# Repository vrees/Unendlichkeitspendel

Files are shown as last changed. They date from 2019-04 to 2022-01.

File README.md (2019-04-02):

GitHub Logo

Maker Media GmbH
*** 

# Unendlichkeitspendel

Ein faszinierender Hingucker ist das Pendel-Interruptus,
das ewig pendelt und nie mit der rotierenden Lochscheibe
kollidiert, die es immer wieder durchqueren muss.

von Martin Simeth

Den vollständigen Artikel mit der Bauanleitung gibt es in der Make-Ausgabe 2/19

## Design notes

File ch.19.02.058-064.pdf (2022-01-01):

# Unendlichkeits-Pendel

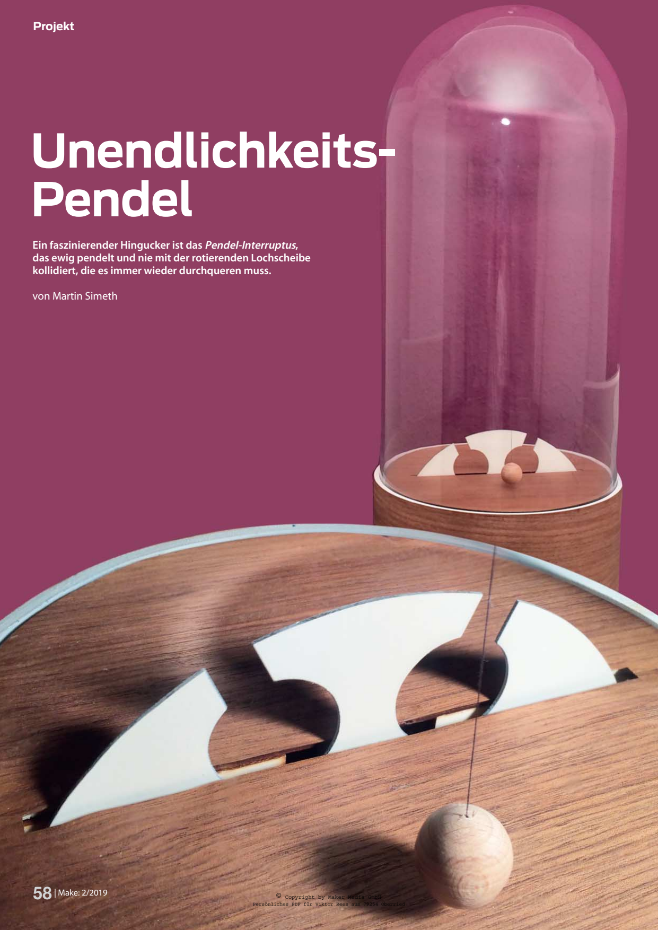
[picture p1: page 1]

58| Make: 2/2019

### Projekt

Ein faszinierender Hingucker ist das Pendel-Interruptus, das ewig pendelt und nie mit der rotierenden Lochscheibe kollidiert, die es immer wieder durchqueren muss.

von Martin Simeth

© Copyright by Maker Media GmbH

Persönliches PDF für Viktor Rees aus 79254 Oberried

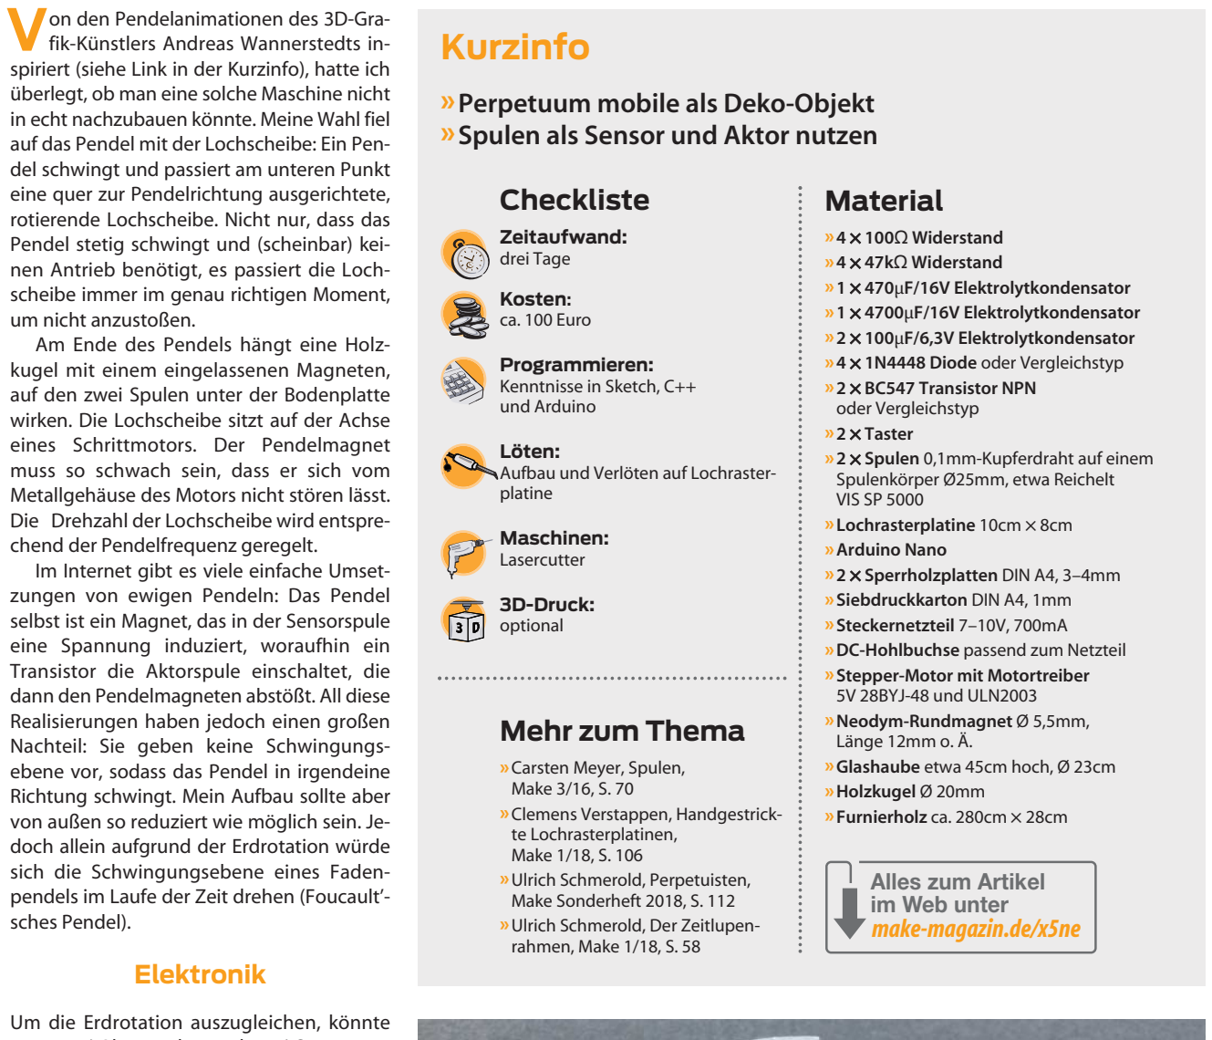
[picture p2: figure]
Von den Pendelanimationen des 3D-Gra-; fik-Künstlers Andreas Wannerstedts in-; eine quer zur Pendelrichtung ausgerichtete,; um nicht anzustoßen. Am Ende des Pendels hängt eine Holz - kugel mit einem eingelassenen Magneten,; eines Schrittmotors. Der Pendelmagnet muss so schwach sein, dass er sich vom; chend der Pendelfrequenz geregelt.; zungen von ewigen Pendeln: Das Pendel; eine Spannung induziert, woraufhin ein Transistor die Aktorspule einschaltet, die; Realisierungen haben jedoch einen großen Nachteil: Sie geben keine Schwingungs -; sich die Schwingungsebene eines Faden-; sches Pendel).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

spiriert (siehe Link in der Kurzinfo), hatte ich überlegt, ob man eine solche Maschine nicht in echt nachzubauen könnte. Meine Wahl fiel auf das Pendel mit der Lochscheibe: Ein Pendel schwingt und passiert am unteren Punkt

rotierende Lochscheibe. Nicht nur, dass das Pendel stetig schwingt und (scheinbar) keinen Antrieb benötigt, es passiert die Lochscheibe immer im genau richtigen Moment,

auf den zwei Spulen unter der Bodenplatte wirken. Die Lochscheibe sitzt auf der Achse

Metallgehäuse des Motors nicht stören lässt. Die Drehzahl der Lochscheibe wird entspre-

Im Internet gibt es viele einfache Umset-

selbst ist ein Magnet, das in der Sensorspule

dann den Pendelmagneten abstößt. All diese

ebene vor, sodass das Pendel in irgendeine Richtung schwingt. Mein Aufbau sollte aber von außen so reduziert wie möglich sein. Jedoch allein aufgrund der Erdrotation würde

pendels im Laufe der Zeit drehen (Foucault’ -

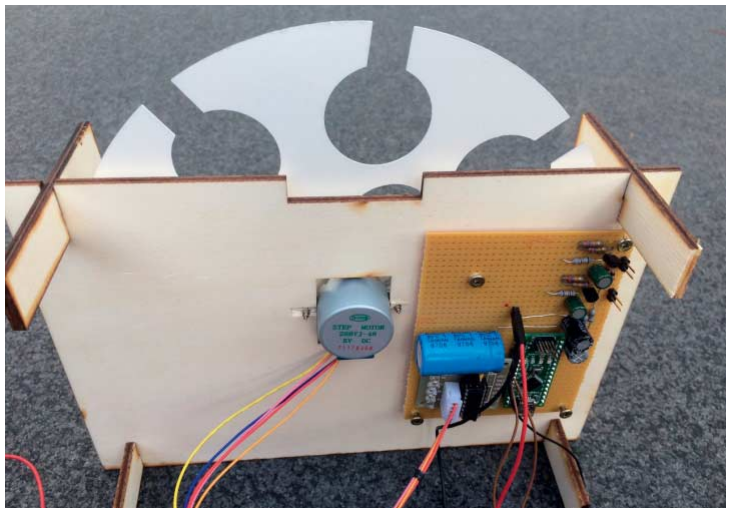
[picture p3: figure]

man zwei Aktorspulen und zwei Sensorspulen nutzen. Die intelligentere Lösung ist es, nur zwei Spulen einzubauen und diese abwechselnd sowohl als Sensor- als auch als Aktorspule einzusetzen. Die Steuerung hierfür übernimmt ein Arduino Nano, der über ein wenig Elektronik mit den Spulen verbunden wird.
Für den Spulenkörper habe ich gebräuchliche Lautsprecherspulen verwendet, bei denen ich den originalen Draht gegen 0,1mm-Kupferdraht ausgetauscht und davon so viel Draht aufgewickelt habe, bis der Spulenkörper voll war. Die exakte Impedanz der Spulen ist nicht wichtig, da die Software Abweichungen gut ausgleicht. Allerdings ist eine hohe Induktivität der Spulen für das Pendel hilfreich.
Über R4 und D1 beziehungsweise R8 und D3 werden die Kondensatoren C1 und C2 aufgeladen. Dabei prüft ein A/D-Wandler des Arduinos an den Spannungsteilern R2/R3 und R6/R7 permanent, ob eine Spannungs-
Make: 2/2019 | 59

Montage der Teile für die Lochscheibe und aufgebaute Elektronik

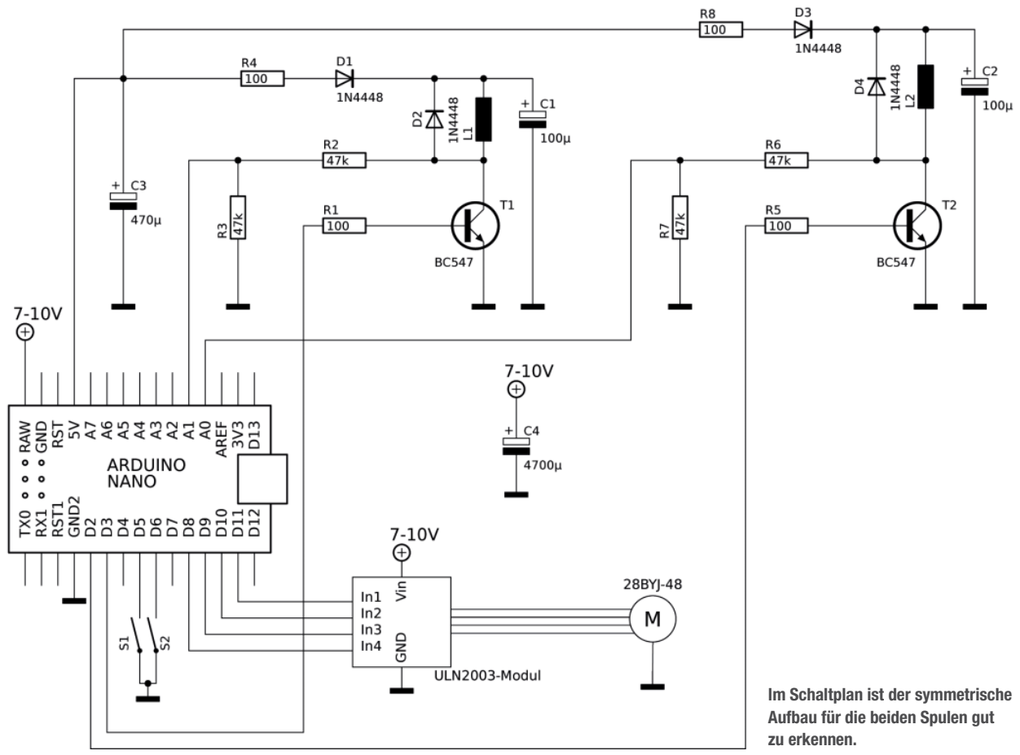
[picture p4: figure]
Im Schaltplan ist der symmetrische Aufbau für die beiden Spulen gut zu erkennen.

induktion aufgrund der Überquerung des Magneten an der Spule L1 oder L2 auftritt. Ist das der Fall, schaltet der Arduino den Transistor T1 oder T2, und der Kondensator C1 oder C2 entlädt sich über eine der Spulen, um das magnetische Pendel anzutreiben. D2 und D4 sind Freilaufdioden: Sie verhindern beim Abschalten der Spulen Spannungsspitzen. Die Spannungsversorgung der Pendelelektronik wird vom Arduino gespeist.

## Software

Beim Start der Software sollte das Pendel nicht schwingen, da in setup() zuerst das Spannungspotenzial der Spulen im Ruhe -zustand des Pendels gemessen wird. Nach Anstoßen des Pendels wird die Schwingungsdauer Period gemessen, indem man die Zeit zwischen dem (n)-ten, und dem (n+3)-ten Durchgang an einer der beiden Spulen misst. In der Hauptroutine loop() wird nun per Abfrage permanent die Spulenspannung mit der Ruhespannung Mean-CoilVoltage verglichen. Wird die Ruhespannung unterschritten, erkennt die Software ein Überstreichen der entsprechenden Spule.
Die Software kann nach jedem erkannten Ereignis die aktuelle Position des Pendels bestimmen. Es werden vier wichtige Positionen unterschieden: zwischen den zwei Spulen (Innendurchgang), außerhalb einer Spule (Außendurchgang A oder B), Transit (tiefster Punkt des Pendels, beim Passieren der Lochscheibe). Um festzustellen, wo sich das Pendel befindet, misst man die Zeit zwischen dem (n)-ten und dem (n+1)-ten Durchgang an einer Spule und vergleicht diese Zeit mit der halben Periodendauer. Ein Außendurchgang ist kürzer als der Innendurchgang. Der Transitzeitpunkt ist nur indirekt messbar. Er findet immer kurz nach der Detektion eines Innendurchgangs statt.
Ein Maß für die Auslenkung des Pendels ist die Zeit, die ein Innendurchgang (Passage) dauert. Ändert sich diese Zeit nicht mehr, ist das Pendel eingeschwungen und das System läuft so stabil, dass die Lochscheibe gestartet werden kann. Sobald die erste der beiden Spulen einen Innendurchgang detektiert, kann anhand der Variablen Passage die Zeit bis zum erwarteten Transit an der Lochscheibe berechnet werden. Sie findet im eingeschwungenen Zustand in etwa der Hälfte der Zeit eines kompletten Innendurchgangs statt. Die Spulen werden mit dem Pendeltimer aktiviert: Nach der Detektion eines Außendurchgangs an einer Spule wird die jeweils andere Spule für eine Zeit COIL_ON_TIME eingeschaltet, um das Pendel zurückzutreiben. Anschließend wird für die Zeit COIL_RELAX_TIME verhindert, dass die gerade bestromte Spule als Sensor verwendet wird.

## Mechanischer Aufbau

Die Pendellänge bei der verwendeten Glasglocke beträgt etwa 43cm. Ein längeres Pendel schwingt langsamer, was unserer Regelung entgegenkommt. Bevor jedoch mit der später genutzten Glasglocke gearbeitet wird, sollte der Magnet zuerst mittels Bindfaden an einem Stativ befestigt und

60| Make: 2/2019

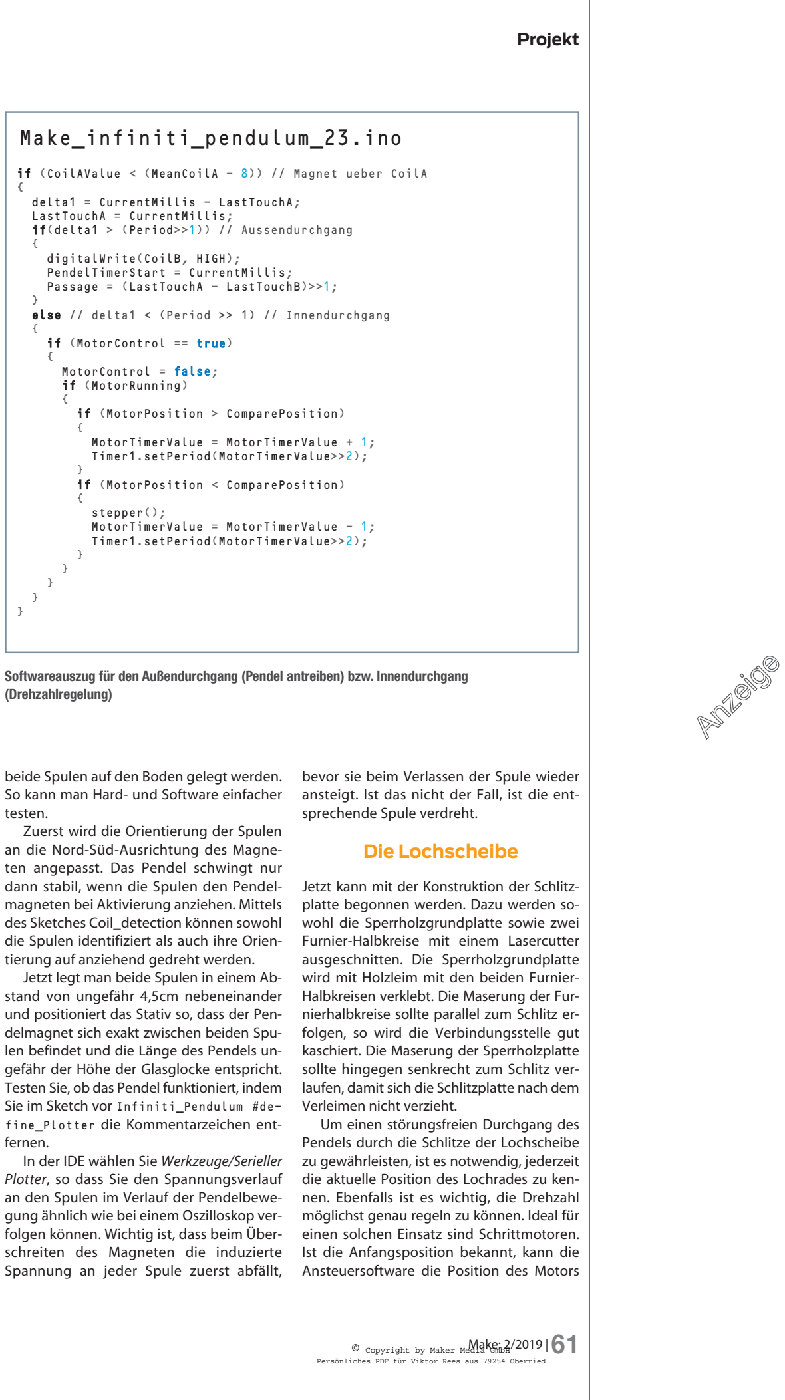
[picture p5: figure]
testen. Zuerst wird die Orientierung der Spulen an die Nord-Süd-Ausrichtung des Magne- ten angepasst. Das Pendel schwingt nur; magneten bei Aktivierung anziehen. Mittels des Sketches Coil_detection können sowohl; tierung auf anziehend gedreht werden.; stand von ungefähr 4,5cm nebeneinander; fine_Plotter die Kommentarzeichen ent- fernen.; schreiten des Magneten die induzierte Spannung an jeder Spule zuerst abfällt,; sprechende Spule verdreht.; Die Lochscheibe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

beide Spulen auf den Boden gelegt werden. So kann man Hard- und Software einfacher

dann stabil, wenn die Spulen den Pendel-

die Spulen identifiziert als auch ihre Orien-

Jetzt legt man beide Spulen in einem Ab-

und positioniert das Stativ so, dass der Pendelmagnet sich exakt zwischen beiden Spulen befindet und die Länge des Pendels ungefähr der Höhe der Glasglocke entspricht. Testen Sie, ob das Pendel funktioniert, indem Sie im Sketch vor Infiniti_Pendulum #de-

In der IDE wählen Sie Werkzeuge/Serieller Plotter, so dass Sie den Spannungsverlauf an den Spulen im Verlauf der Pendelbewegung ähnlich wie bei einem Oszilloskop verfolgen können. Wichtig ist, dass beim Überbevor sie beim Verlassen der Spule wieder ansteigt. Ist das nicht der Fall, ist die ent-

Jetzt kann mit der Konstruktion der Schlitz-

wird mit Holzleim mit den beiden Furnier-Halbkreisen verklebt. Die Maserung der Furnierhalbkreise sollte parallel zum Schlitz erfolgen, so wird die Verbindungsstelle gut

sollte hingegen senkrecht zum Schlitz verlaufen, damit sich die Schlitzplatte nach dem

Pendels durch die Schlitze der Lochscheibe zu gewährleisten, ist es notwendig, jederzeit die aktuelle Position des Lochrades zu kennen. Ebenfalls ist es wichtig, die Drehzahl möglichst genau regeln zu können. Ideal für

Ist die Anfangsposition bekannt, kann die if (CoilAValue <(MeanCoilA - 8)) // Magnet ueber CoilA

else // delta1 < (Period >> 1) // Innendurchgang

Softwareauszug für den Außendurchgang (Pendel antreiben) bzw. Innendurchgang

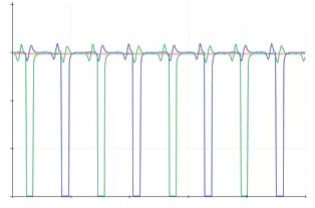
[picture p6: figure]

mitzählen. Meine Wahl fiel auf einen Schrittmotor mit 4096 Schritten pro Umdrehung – so kann die Software binär und damit zeitsparend rechnen. Allerdings gibt es aufgrund des Getriebes, der in den benutzten Motoren verbaut ist, auch ein erhöhtes Spiel, was die Genauigkeit der ganzen Apparatur begrenzt.
Der Motor wird mit der mitgelieferten Ansteuerelektronik mit dem Arduino verbunden. Der verwendete Motor erzeugt starke Störungen auf der Versorgungsspannung, weshalb der Kondensator C4 nahe an der Versorgungsspannung der Ansteuerelektronik platziert wird. Da die Leuchtdioden der

Ansteuerelektronik später durch die Schlitzplatte leuchten würden, kann man sie (oder ihre Vorwiderstände) auslöten. Die Pfostenstecker habe ich ebenfalls ausgelötet und rückwärts wieder eingelötet – so lässt sich die Ansteuerelektronik gut mit der Lochrasterplatine verbinden.
Die Drehzahl des Motors wird mit dem Mikrosekunden-Timer TimerOne und der Routine Stepper() kontrolliert, der vorgibt, alle wie viel Mikrosekunden der Motor einen Schritt weiter drehen soll. Bei 8 Löchern in der Scheibe benötigt der verwendete Motor von Loch zu Loch 512 Schritte. Aus der Periodendauer des Pendels wird ein passender

Wert für die Drehzahl des Motors berechnet: MotorTimerValue = Period*1000/1024. 1024 entspricht 512 x 2, da das Pendel während einer Periode zwei mal durch die Loch -scheibe schwingt. Diese Rechnung lässt sich in C mit einem Rechtsshift (>>)sehr schnell berechnen, 1024 entspricht nämlich 2¹⁰: MotorTimerValue = (Period*1000)>10. Die Motoraufhängung wird aus Sperrholz ausgeschnitten und der Motor mit kleinen Holzschrauben fixiert. Die Lochscheibe wird ebenfalls mittels Lasercutter erstellt und muss plan und formstabil und leicht sein, weshalb Siebdruckkarton zum Einsatz kommt. Beim Montieren der Lochscheibe auf die Achse des Motors ist darauf zu achten, dass die Scheibe nirgends schleift und nicht eiert. Dazu startet man den Sketch Motortest, der den Motor langsam drehen lässt. Unter Umständen muss der Motor durch Zurechtbiegen der Befestigungsfahnen noch ausgerichtet werden. Gegen zu viel Spiel helfen die Verstärkungsscheiben, die in der Vorlagendatei enthalten sind (Downloads siehe Link in der Kurzinfo). Ich habe die Scheibe bei laufendem Motor ausgerichtet und sie anschließend, ebenfalls bei laufendem Motor, mit Heißkleber vorsichtig auf der Motorachse fixiert.

## Synchronisierung von Pendel und Motor

Aufgrund unterschiedlicher mechanischer und elektrischer Gegebenheiten, müssen in der Software einige Parameter angepasst werden, die nur empirisch ermittelt werden können. Das Pendel wird zunächst nicht durch die Lochscheibe geschickt, sondern

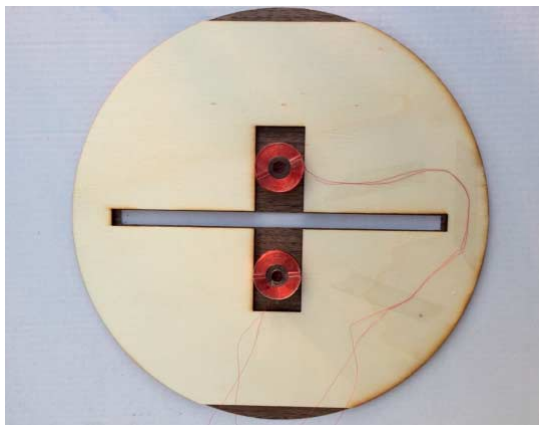
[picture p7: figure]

62| Make: 2/2019

In der Arduino-IDE überprüfen Sie, ob die Spulen richtig ausgerichtet sind. So in etwa soll die Ausgabe aussehen (siehe Text).

Die Spulen werden mittig mit gleichem Abstand zum Schlitz auf die Unterseite des Furniers in die entsprechende Aussparung geklebt. Durch die Aussparung sitzen die Spulen später möglichst dicht unter dem Pendel.

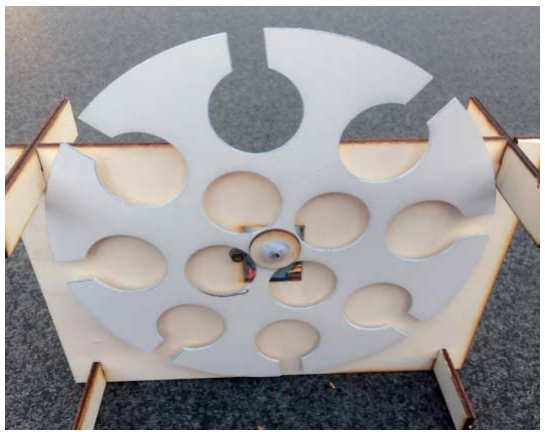
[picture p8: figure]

Die inneren Löcher der Lochscheibe dienen der Gewichtseinsparung, und man kommt zudem nach der Montage noch an die Befestigungsschrauben des Motors heran.

Lochscheibe und Pendel agieren erst einmal unabhängig voneinander. Dennoch lässt sich die Motorregelung auf diese Weise überprüfen und feintunen.
Der Motor der Lochscheibe ist inaktiv, bis das Pendel stabil schwingt. Als Maß hierzu dient die Zeit, die ein Innendurchgang (startend bei Spule A) benötigt (Passage). Dazu wird die Innendurchgangszeit gleitend gemittelt. Da der Zielwert der Innendurchgangszeit nicht bekannt ist, wird anschließend die Varianz der Innendurchgangszeiten gleitend gemittelt (VarianzPassage). Fällt die Varianz unter einen vorgegebenen Wert, ist das Pendel eingeschwungen.
Der Start des Motors muss exakt im Transit des Pendels erfolgen. Da hierfür kein Sensor vorgesehen ist, muss jeweils der Startzeitpunkt eines Innendurchgangs (an Spule A) als Maß herangezogen werden. Zu diesem Zeitpunkt muss die halbe Innendurchgangszeit (plus ein später zu ermittelnder Korrekturfaktor COIL_MIDDLE_COM-PENSATION) addiert werden, dann startet der Motor. Wenn der Motor startet, kennen wir dessen Motorposition (MOTOR_START_ POS/Motorposition). Für die Regelung interessiert uns allerdings die Motorposition, die der Motor zum Startzeitpunk des Innendurchgangs (Compareposition) gehabt hätte (wäre er da schon gelaufen). Diese fiktive Position liegt in der Vergangenheit, wir müssen von Motorposition also etwas abziehen:
ComparePosition | = | Motorposition | –
(1024/Period) * Passage

Es ist bekannt, dass 1024 Motorschritte für eine Pendelperiode Period benötigt werden. Dieser Quotient wird daher mit der gemessenen Zeit multipliziert, die zwischen Innendurchgang und Transit liegt und man erhält den Zielwert ComparePosition für die Motorregelung für jeden weiteren Innendurchgang an Spule A. Da die Software die Motorposition mitzählt, erkennt das Programm, ob

## Make_infiniti_pendulum_23.ino

if (MotorTimerValue == 0)
MotorTimerValue = ((long)Period * 2000)/(512 + PauseAtTransit - 1); else
MotorTimerValue = MotorTimerValue << 2;

Timer1.initialize(MotorTimerValue >> 2);
#ifdef Monitor

Serial.println("Periode MotorTimerValue"); Serial.print(Period);
Serial.print(",");
Serial.println(MotorTimerValue>>2); Serial.println("");
Serial.println("PassageTime Varianz"); #endif

Ausgabe der Einschwingphase

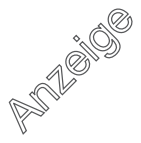
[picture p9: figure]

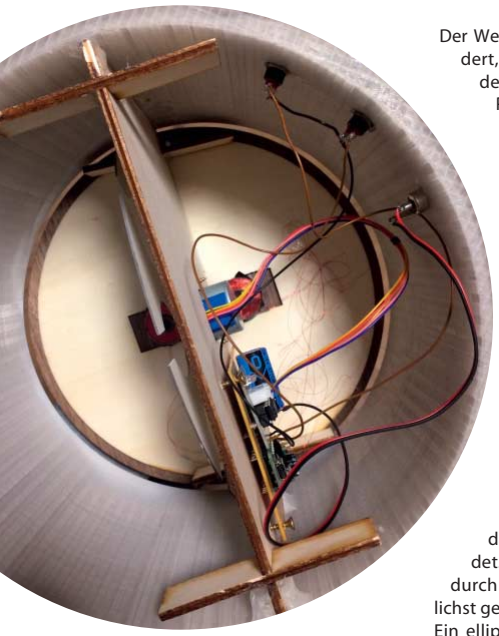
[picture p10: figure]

das Loch früher oder später am Innendurchgang ankommt und erhöht – oder verringert die Motordrehzahl durch Variation des MotorTimeValue. Zur Überprüfung der Regelung kann man in der Software #define Monitor aktivieren (alles andere deaktivieren) und das Zusammenspiel zwischen Lochscheibe und Pendel im Monitor der Arduino-Entwicklungsumgebung anschauen.
Das Programm wird bei ruhendem Pendel gestartet, damit die Software die Spulenruhespannung messen kann. Anschließend wird das Pendel angestoßen. Im Programmteil setup() wird zuerst die Pendelperiode und die daraus resultierende initiale Motordrehzahl ausgegeben. Jetzt kann man verfolgen, wie sich das Pendel einschwingt. Wird der Wert von Varianz-Passage unterschritten, startet der Motor. Die angezeigten Größen sind nun die jeweils gemessene Motorposition und die aktuelle Motordrehzahl MotorTimerValue. Je exakter der Wert zum Start des Motors ist, desto schneller wird der eingeschwungene Zustand erreicht. Daher gibt es in der Software die Möglichkeit, alternativ zur Bestimmung in der Routine setup() einen langfristig gemittelten Wert zur Initialisierung von MOTOR_TIMER_VALUE zu verwenden.

Der Wert MOTOR_START_POS wird so geändert, dass ComparePosition ungefähr den Wert 250 annimmt. Motor und Pendel können gestoppt werden, indem beide Taster zugleich gedrückt werden, die Lochscheibe wird dann wieder in der Anfangsposition stehenbleiben. Wenn das System so weit
funktionstüchtig ist, dass die Regelung nach Start des
Motors schnell und stabil
einsetzt, können alle Kom -ponenten zusammengefügt
werden, um zu überprüfen,
ob das Pendel auch tatsächlich passgenau das jeweilige Loch trifft. Dazu verbindet man die Schlitzplatte mit der Motorhalterung. Nach Start des Programms wird mit den beiden Tasten die Lochscheibe so gedreht, dass sich ein Loch genau oben befindet. Zum Schluss wird das Pendel durch die Lücke hindurch in einer möglichst geradlinigen Bewegung angeschubst. Ein elliptisch schwingendes Pendel benötigt mehr Platz als ein gerad liniges Pendel, aber die Regelung des Pendels korrigiert dies im Laufe der Zeit.
Im Prinzip sollte jetzt schon alles funktionieren, leider triggern die Spulen aber nicht immer exakt in der Spulenmitte, so dass der Korrekturfaktor COIL_MIDDLE_COMPENSATI-ON zum synchronen Motorstart variiert werden muss. Ist der Korrekturfaktor zu klein, bleibt das Pendel schon am ersten Loch hängen. Ist der Korrekturfaktor zu groß, eckt das Pendel beim Zurückschwingen an der Hinterseite des nächsten Lochs an. Es kann etwas dauern, bis der ideale Wert für COIL_MIDDLE_COMPENSATION gefunden ist, da wir bei jedem Versuch warten müssen, bis das Pendel eingeschwungen ist. Ein Notaus in der Software stoppt die Lochscheibe, wenn das Pendel nicht wie erwartet die Spulen abwechselnd überstreicht. An D13 (LED) können Sie ein Stroboskop anschließen, um die genaue Position von Pendel und Lochscheibe im Transit zu erkennen.

## Veredelung

Eine passende Glasglocke findet sich im Internet. Mithilfe von transluzentem 2K-Kleber wird möglichst mittig an der inneren Oberseite der Glasglocke ein Faden angeklebt. Für das Pendel habe ich eine massive Holzkugel mit Durchmesser 20mm verwendet. Wichtig ist, dass in der Ruhestellung der Faden mittig in einem Loch der Lochscheibe hängt und die Kugel möglichst flach über die Schlitzplatte pendelt. Der Magnet und der Faden werden ebenfalls mit Kleber an der Kugel befestigt.
Für den Sockel gibt es eine 3D-Drucker-Vorlage mit Führungsnut für die Motoraufhängung. Die andere Seite der Aufhängung wird so eingeklebt, dass die Lochscheibe und Grundplatte mittig im Sockel liegt. Anschließend noch die Taster und die DC-Buchse verkabeln. Ein schönes Äußeres erhält der Sockel, indem man ihn mit Furnier beklebt. Um bei aufgesetzter Glasglocke das Pendel anzustoßen, versetzt man das ganze Objekt zum Start einfach ruckartig.

## Variationen

Einen Autostart des Pendels hatte ich versucht zu implementieren, scheiterte aber an der Chaostheorie: Schon minimale Änderungen der Startbedingungen können zu sehr unterschiedlichen Ergebnissen führen. Vielleicht hat einer der Leser hierzu eine zielführende Idee. Statt die Lochscheibe einfach nur konstant in eine Richtung drehen zu lassen, könnte man die Scheibe vorund zurückdrehen lassen, Zufallszahlengenerator-gesteuert mal pausierend oder gar mit der doppelten Geschwindigkeit drehen. Wählt man einen Schrittmotor ohne Getriebe, ist die Positioniergenauigkeit deutlich erhöht. Dadurch sollten sich die Löcher der Lochscheibe noch deutlich verkleinern
lassen. | —fls

64| Make: 2/2019

## Make_infiniti_pendulum_23.ino

// Die empirisch zu ermittelnden Parameter:
#define MOTOR_START_POS 360 | // so wählen, dass ComparePosition ~250 ist

#define COIL_MIDDLE_COMPENSATION 85 | // Für das reibungsfreie Zusam-

menspiel anpassen
#define MOTOR_TIMER_VALUE 0 // Wenn im "Monitor" stabil: Wert hier eintragen

// Debug Möglichkeiten für Pendel (Plotter) und die Regelung (Monitor) jeweils nur einen auswählen!
// #define Monitor | // Alle Parameter der Pendel-Motor Regelung anzeigen
// #define Plotter | // Plot-Ausgabe für das Pendel

In den Sockel wird von oben die Motoraufhängung mit verklebter Grundplatte geschoben.

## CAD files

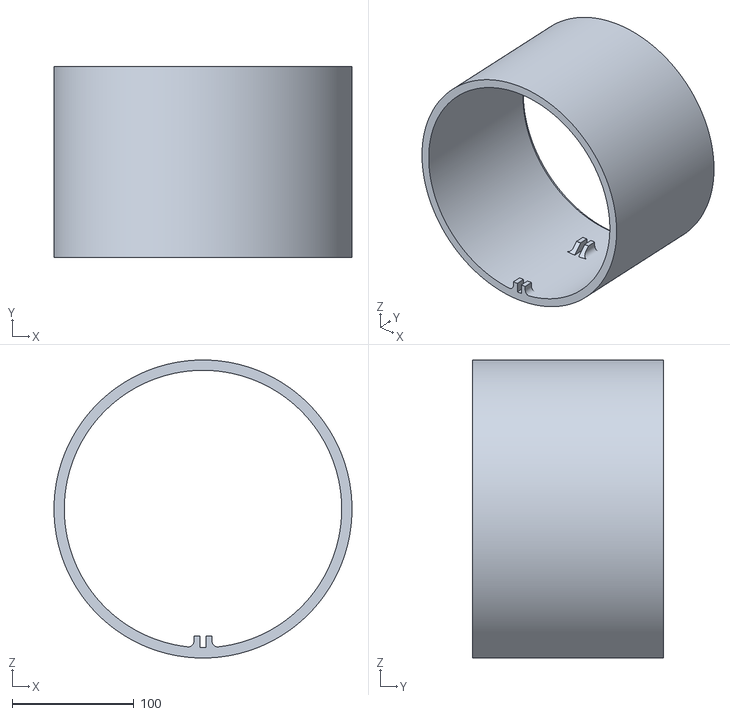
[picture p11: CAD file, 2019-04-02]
Sockel/Sockel.stl
245.0 x 157.0 x 245.0

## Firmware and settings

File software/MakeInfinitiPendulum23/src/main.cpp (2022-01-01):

#include <Arduino.h>

#include "TimerOne.h"
#define CoilA 2
#define CoilB 3
#define LED 13
#define LOOP_DELAY 3
#define COIL_ON_TIME 100
#define COIL_RELAX_TIME 250
#define MOTOR_START_POS 360  // so wählen, dass ComparePosition ~250 ist
#define COIL_MIDDLE_COMPENSATION 85
#define MOTOR_TIMER_VALUE 0   // Wenn bekannt: Wert hier eintragen

 #define Monitor
// #define Plotter

void stepper();       // ISR für den Schrittmotor
byte CheckButtons();  // Tasten eingabe

int  MotorTimerValue = MOTOR_TIMER_VALUE;    
int  MotorPosition;   // Motor Position beim Transit
int  MeanCoilA;
int  MeanCoilB;
bool MotorRunning = false;
long PendelTimerStart = 0;
long PendelTimerValue;
unsigned long LastTouchA;
unsigned long LastTouchB;
int  ComparePosition;
long Passage;
long MeanPassage;
long VarianzPassage;
int  Period;
byte Direction = 1;
bool MotorControl = false;
bool MotorDelay = false;
byte Shutdown = 0;
byte PauseAtTransit = 0;

void setup() 
{
  long CoilATouches[8];
  DDRB = 0x2F;    // Motor und LED sind output
  DDRD = 0x0C;    // Tasten sind input, Spulen output
  PORTD = 0x60;   // Pullups für die Tasten

  Serial.begin(9600);
  MeanCoilA = analogRead(A0);   // Ruhe-Spulenspannung
  MeanCoilB = analogRead(A1);
 
  while (analogRead(A0) < (MeanCoilA + 8))  
  {       // Loch-Justage möglich, bis zum ersten Spulen Transit
    delay(3);
    CheckButtons();
  }

  for (int i=0; i<8; i++)
  {
    while (analogRead(A1) < (MeanCoilB + 8))  
    { // Magnet ist über CoilA
    }
    CoilATouches[i]=millis();
    while (analogRead(A1) > (MeanCoilB - 8))  
    { // Warte bis Magnet weg ist
    }
  }
  Period = (CoilATouches[6] - CoilATouches[2])>>1;  // Periode abschätzen
 
  
  if (MotorTimerValue == 0)
    MotorTimerValue = ((long)Period * 2000)/(512 + PauseAtTransit - 1);
  else              
    MotorTimerValue = MotorTimerValue << 2; // Wenn MotorTimerValue bekannt ist (Deklaration) diesen nehmen !!!!

  Timer1.initialize(MotorTimerValue >> 2);

#ifdef Monitor
  Serial.println("Periode  MotorTimerValue");
  Serial.print(Period);
  Serial.print(",");
  Serial.println(MotorTimerValue>>2);
  Serial.println("");
  Serial.println("PassageTime  Varianz");
#endif
}
 
void loop() {
  int CoilAValue;
  int CoilBValue;
  long delta1;
  long delta2;
  unsigned long CurrentMillis;
  
  CurrentMillis = millis();

/******************************************/  
/* Behandle Coil A                          */
/******************************************/
  CoilAValue = analogRead(A0);  // Lese CoilA Spannung
  if (PendelTimerStart == 0)    // Wenn CoilA nicht gefeuert hat, dann:
  {
    if (CoilAValue < (MeanCoilA - 8)) // Magnet über CoilA ?
    {
      delta1 = CurrentMillis - LastTouchA;
      LastTouchA = CurrentMillis;
      if(delta1 > (Period>>1))
      {
        digitalWrite(CoilB, HIGH);
        PendelTimerStart = CurrentMillis;
        Passage = (LastTouchA - LastTouchB)>>1;
        if(!MotorRunning)
        {   // Berechne die Varianz der Passage, um stabilität des Pendulums zu eruieren
          delta1 = Passage - (MeanPassage>>5); // Abweichung old Mean
          MeanPassage = MeanPassage + delta1;
          delta2 = Passage - (MeanPassage>>5); // Abweichung new Mean
          VarianzPassage = (VarianzPassage - VarianzPassage>>5) + delta1 * delta2;

#ifdef Monitor
  Serial.print(Passage);
  Serial.print(",");
  Serial.println(VarianzPassage);
#endif
        }
      }
      else // delta1 < (Period >> 1)
      {
        if (MotorControl == true)
        {
          MotorControl = false;
          if (MotorRunning)
          {
            if (MotorPosition > ComparePosition)
            {
              MotorTimerValue = MotorTimerValue + 1;
              Timer1.setPeriod(MotorTimerValue>>2);
            }
            if (MotorPosition < ComparePosition)
            {
              stepper();
              MotorTimerValue = MotorTimerValue - 1;
              Timer1.setPeriod(MotorTimerValue>>2);
            }
#ifdef Monitor
   Serial.print(MotorPosition);
   Serial.print(",");
   Serial.println(MotorTimerValue>>2);
 #endif
          }
          else //  if (!MotorRunning)
          {
            if (VarianzPassage < 100)  // Warte, bis Pendel stabil schwingt, befor Motor gestartet wird
            {
#ifndef Plotter
              MotorRunning = true;
              MotorPosition = MOTOR_START_POS;    // Hier müssen wir bei dem nächsten Transit wieder hin!
              Passage = Passage + COIL_MIDDLE_COMPENSATION; // Bei Motorstart erstmalig die Kompensation berücksichtigen
              Direction = 1;
              delay(Passage);  // Warte, bis Pendel im Transit ist
              Timer1.attachInterrupt(stepper);  // Und starte motor
              ComparePosition = MotorPosition - (int)(((long)(Passage<<10))/Period); // Theoretische Motor Position kurz vorher, als Pendel über CoilA war
#endif

#ifdef Monitor
  Serial.println(" ");
  Serial.println("Motor Started");
  Serial.println("ComparePosition");
  Serial.print(ComparePosition);
  Serial.println(" ");
  Serial.println("ComparePosition  MotorTimerValue");
#endif
            }
          }
        }
      }
    }
  }
  
/******************************************/  
/* Behandle Coil B                          */
/******************************************/
  CoilBValue = analogRead(A1);  // Lese CoilB Spannung
  if (PendelTimerStart == 0)    // Wenn CoilB nicht gefeuert hat, dann:
  {
    if (CoilBValue < (MeanCoilB - 8)) // ist Pendel über CoilB ?
    {
      delta1 = CurrentMillis - LastTouchB;
      LastTouchB = CurrentMillis;
      if(delta1 > (Period>>1))
      {
        digitalWrite(CoilA, HIGH);
        PendelTimerStart = CurrentMillis;
      }
      else
          MotorControl = true;
    }
  }

/******************************************/  
/* Pendel Timer -> Spule aktivieren       */
/******************************************/
  if (PendelTimerStart > 0)
  {
    PendelTimerValue = CurrentMillis - PendelTimerStart;
    if (PendelTimerValue > COIL_RELAX_TIME)
      PendelTimerStart = 0;  // Stoppe timer und ermögliche Sensornutzung der Spulen
    else
    {
      if (PendelTimerValue > COIL_ON_TIME)
        PORTD = (PORTD & 0xF3);  // CoilA und CoilB ausschalten
    }
  }
    
  if (CheckButtons() == 2)  // Shutdown starten, wenn beide Tasten gedrückt
    Shutdown = 1;           // Motor stop in Transit Position

#ifdef Plotter
  Serial.print(CoilBValue);
  Serial.print(",");
  Serial.print(MeanCoilA);  
  Serial.print(",");
  Serial.print(PendelTimerValue << 1);
  Serial.print(",");
  Serial.println(CoilAValue);
#endif

  delay(LOOP_DELAY);
}
 
/******************************************/  
/* ISR Schrittmotor                            */
/******************************************/
void stepper()    // Interrupt Routine, die von Timer 1 alle x Microsekunden (MotorTimerValue) aufgerrufen wird.
{
  static byte Steps;
  static byte Pause;
  if (!MotorDelay)
  {
    if ((MotorPosition != MOTOR_START_POS) || (Pause == 0)) // Sind wir nicht im Transit?
    {                                                       // dann Motor weiterdrehen
      digitalWrite(LED, LOW);                               // Stroboskop LED ausschalten
      Steps = (Steps + Direction) & 0x07;
      MotorPosition = (MotorPosition + (int)Direction);
      MotorPosition = MotorPosition & 0x01FF;               // Wir werten nur die relative motor position aus
      Pause = PauseAtTransit;                               // Pausenlänge im Transit in "IR counts"
      switch (Steps) 
      {
        case 0:
        PORTB = (PORTB & 0xf0) | B00001000;
        break;
        case 1:
        PORTB = (PORTB & 0xf0) | B00001100;
        break;
        case 2:
        PORTB = (PORTB & 0xf0) | B00000100;
        break;
        case 3:
        PORTB = (PORTB & 0xf0) | B00000110;
        break;
        case 4:
        PORTB = (PORTB & 0xf0) | B00000010;
        break;
        case 5:
        PORTB = (PORTB & 0xf0) | B00000011;
        break;
        case 6:
        PORTB = (PORTB & 0xf0) | B00000001;
        break;
        case 7:
        PORTB = (PORTB & 0xf0) | B00001001;
      }
    }
    if (MotorPosition == MOTOR_START_POS)   // in TransitPosition!!!
    {
      digitalWrite(LED, HIGH);  // Schalte Stoboskop LED ein
      if (Pause > 0)
        Pause = Pause - 1;      // Pause im Transit
      if (Shutdown > 0)         // Wenn Shutdown gewünscht:
      {
        PORTB = (PORTB & 0xD0);  // Motor und LED ausschalten
        PORTD = (PORTD & 0xF3);  // Spulen ebenfalls ausschalten
        Timer1.detachInterrupt();
        while(1);                // Wir warten auf "Power loss"
      }
    }
  }
  else // Eine kurze Pause für den Motor
    MotorDelay = false;
}

/******************************************/  
/* Behandlung der Tasten                  */
/******************************************/
byte CheckButtons()
{
  static byte button1 = 0;
  static byte button2 = 0;

    button1++;
    if (digitalRead(5) == HIGH)
      button1 = 0;
 
    button2++;
    if (digitalRead(6) == HIGH)
      button2 = 0;

  if (!MotorRunning)  // Justierung der Lochscheiben Position bevor der Motor läuft
  {
    if ((button1 & 0x0F) == 0x0F)
    {
      Direction = -1;
      stepper();
    }
    if ((button2 & 0x0F) == 0x0F)
    {
      Direction = 1;
      stepper();
    }
  }
  else // Justierung der Lochscheiben Position nach Motorstart
  {
    if ((button1 & 0x1F) == 0x1F)
       MotorDelay = true;
    if ((button2 & 0x1F) == 0x1F)
       stepper();
  }
  return (bool)button1 + (bool)button2; // 0: no press, 1: one key, 2: both keys
}

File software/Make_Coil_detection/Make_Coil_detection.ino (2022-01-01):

#define CoilA 2
#define CoilB 3
void setup() 
{
    //pinMode(CoilA, OUTPUT);
    pinMode(CoilB, OUTPUT);
}

void  loop() 
{
//  digitalWrite(CoilA, HIGH);        // Start Sequenz
  digitalWrite(CoilB, HIGH);        // Start Sequenz
  delay(10000);
//  digitalWrite(CoilA, LOW);        // Start Sequenz
  digitalWrite(CoilB, LOW);        // Start Sequenz
  while(1) {}
}
